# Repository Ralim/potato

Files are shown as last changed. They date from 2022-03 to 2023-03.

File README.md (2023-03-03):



# Potato

OpenSource inline USB-PD Power meter.

...WIP...

## Desired features

- Easy to assemble (No QFN)
- Read device PD capabilities
- Capture USB-PD messages
- Read USB D- / D+ voltages for QC
- Pull resistors for QC control
- UART or USB for datalogging
- Either buttons or encoder for input
- Small LCD display
- DC In/Out port

- Accelerometer or tilt switch for rotation?

## Ideas to explore

- As LVGL is a goal for the UI, consider [prototyping](https://docs.lvgl.io/latest/en/html/get-started/pc-simulator.html) on "real" computer or talking to the PineTime team about their experience about developing [UI in NaCL](https://github.com/AppKaki/lvgl-wasm), allowing feedback from web users. If realized, this may allow more explorative development in a less painful environment as you can skip the slow upload/reboot cycle.

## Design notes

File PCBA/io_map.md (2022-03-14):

Here is the first pass of or [gpio pin mapping](https://user-images.githubusercontent.com/8724975/158108831-fbf8fa47-cd49-4bae-8a7a-24a997bb3a8b.png).

This comes from mcu.kicad_sch, but is broken out for discussion and to be of more immediate use to 
those not versed in Kicad.

As of March 14, Robert is uncomfortable with Pin 16. (Robert's a software guy, so his uneasiness is 
trumped by other boards successfully using Pint 16.) Section 3.2.5 on page 25 describes the versaitle 
pin muxing available on the BL60x parts. It shows that we can populate the five bit mode enum to bring 
it into UART mode.  UNfortunately, the pins default to UART mode SIG1, which maps to UART0_CTS when 
a SIG6 would give us a compliment to our UART1_RX currently on GPIO 7.

Trying to harvest from current code is frustrating.

~/src/bl_mcu_sdk/drivers/bl602_driver/regs/glb_reg.h 
creates a perfectly lovely bitmapped union, which the code signores and splats over its own 
incomprehensible macros and bit-banging.  uart-swap_set is never used. The bits are actually 
set in GLB_UART_Sig_Swap_Set() inside drivers/bl602_driver/std_drv/src/bl602_glb.c

So we're currently researching this. Help welcome.



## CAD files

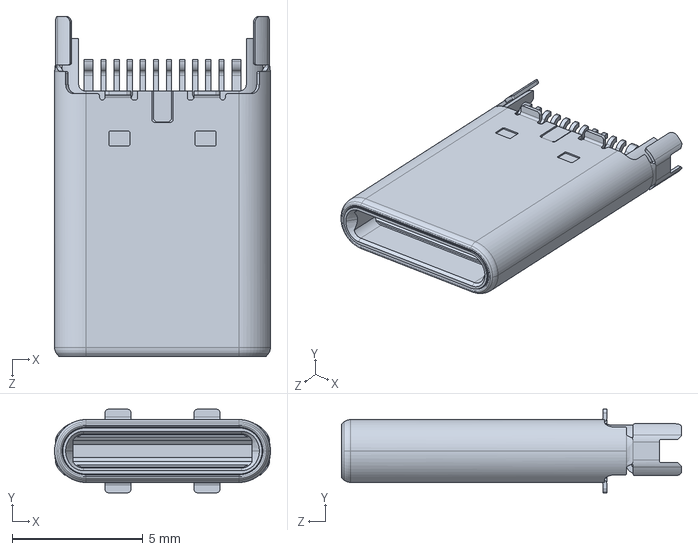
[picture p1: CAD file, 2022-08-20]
PCBA/K3D-DX07P022AA6.STEP
8.25 x 3.20 x 13.0 mm

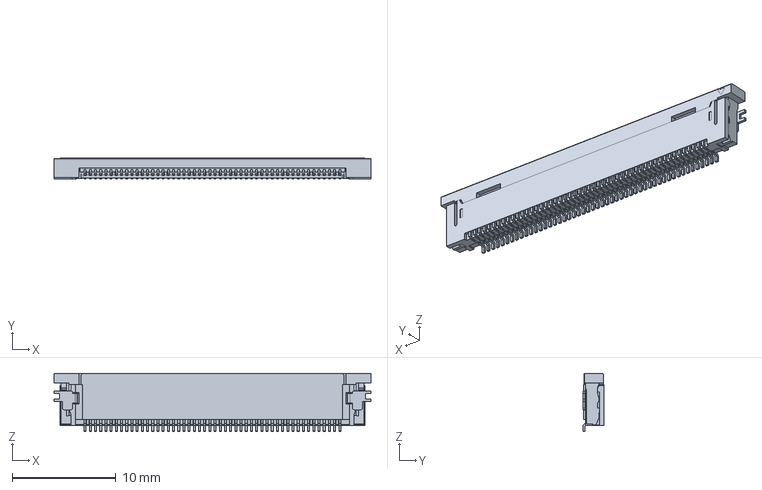
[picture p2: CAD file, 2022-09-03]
PCBA/541325033.stp
30.5 x 2.05 x 5.60 mm

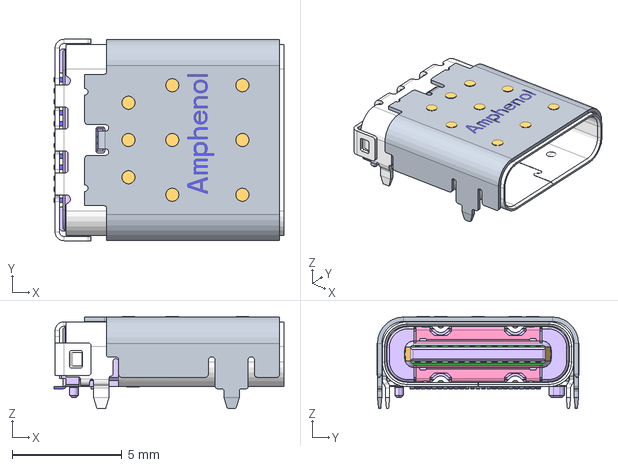
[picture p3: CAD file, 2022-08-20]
PCBA/12401610E4#2A--3DModel-STEP-533217.STEP
10.5 x 9.20 x 4.21 mm

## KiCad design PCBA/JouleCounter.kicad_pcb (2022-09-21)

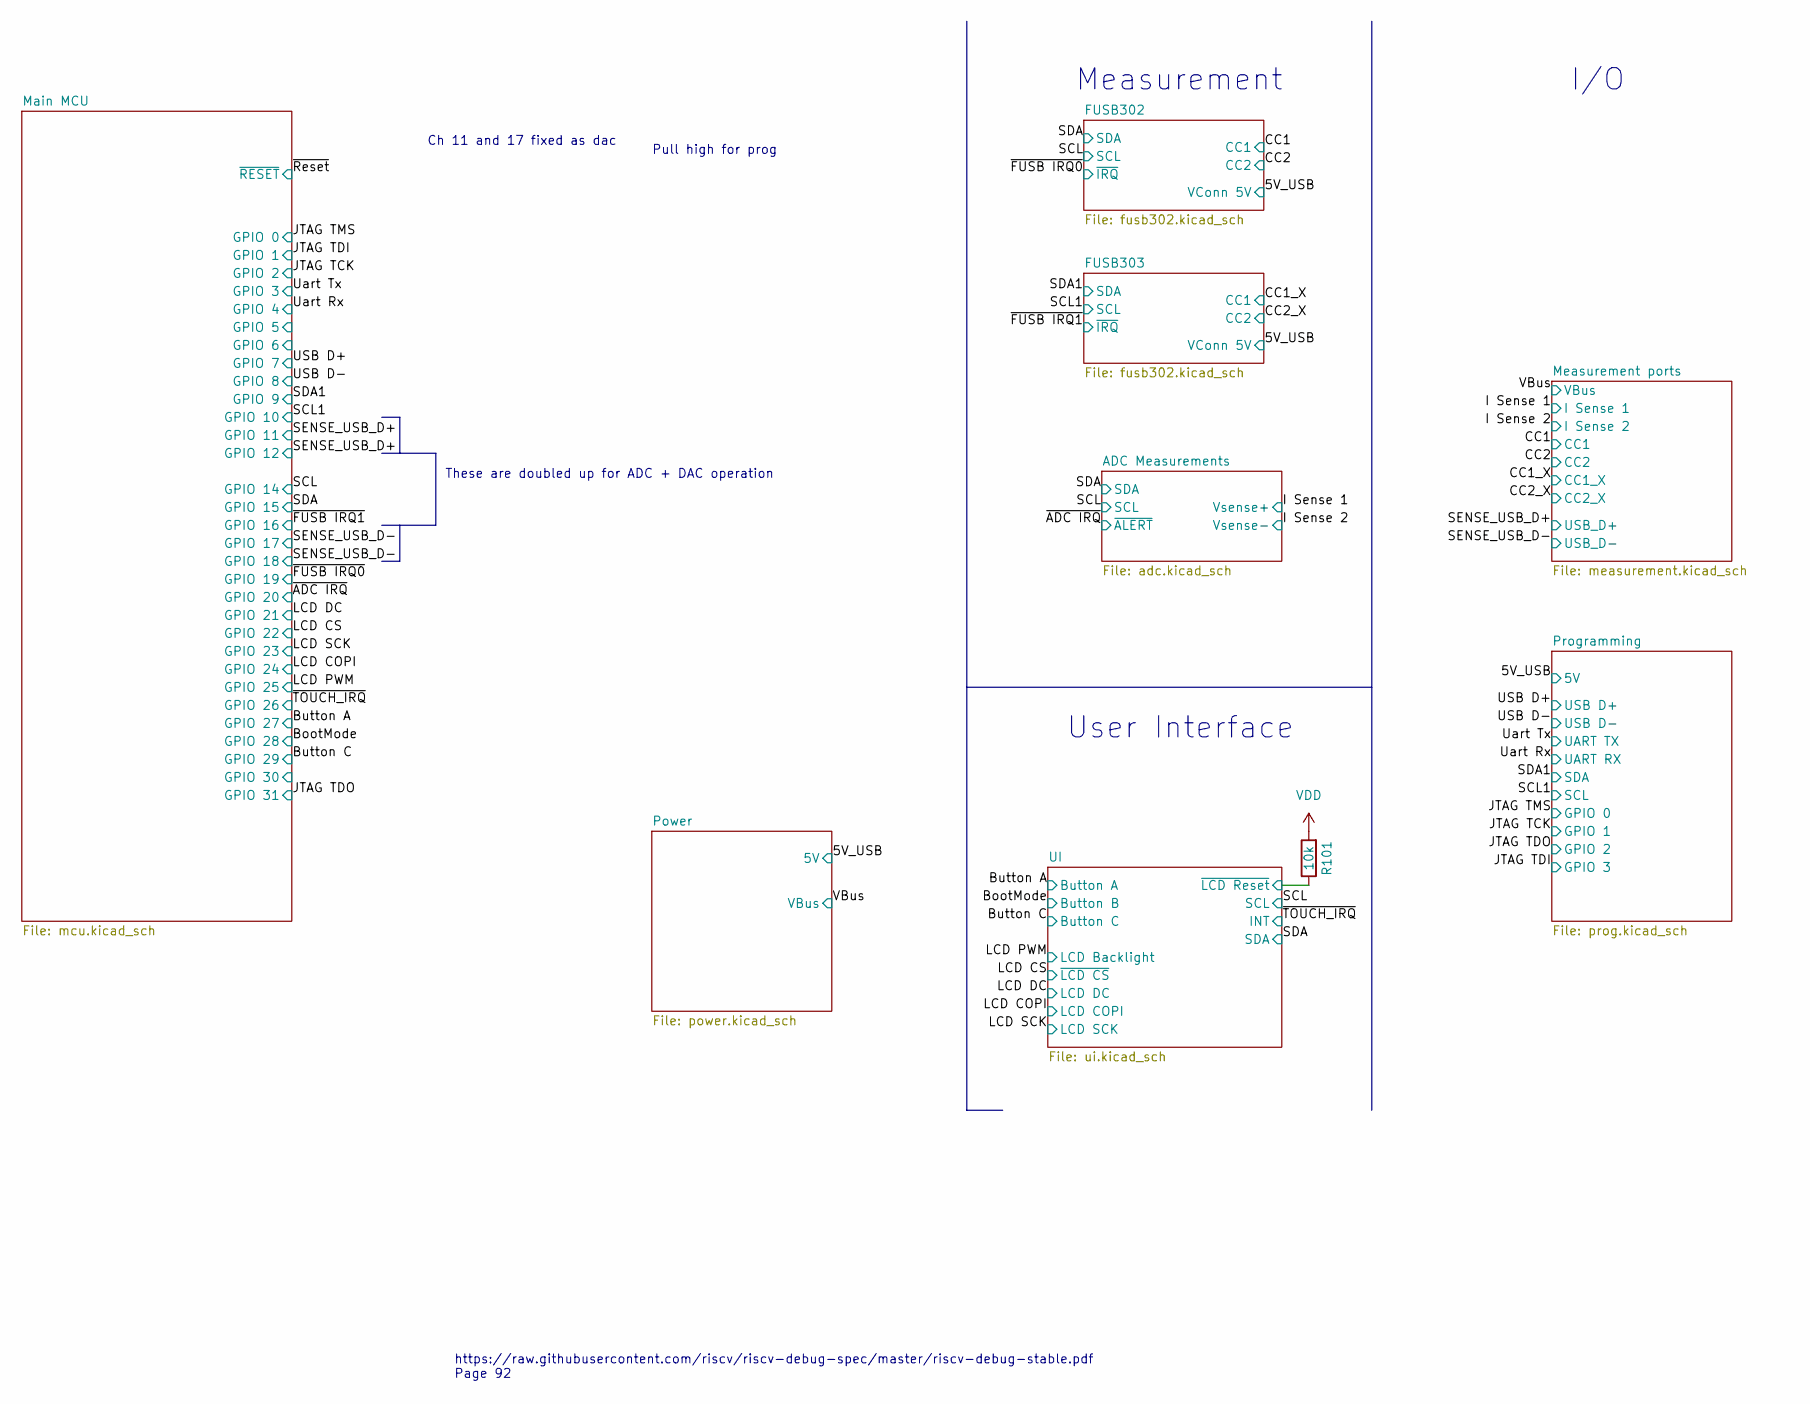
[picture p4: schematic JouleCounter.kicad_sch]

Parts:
R101: 10k; R_0603_1608Metric

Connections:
/UI/~LCD Reset: R101.1; also elsewhere on the board
VDD: R101.2; also elsewhere on the board

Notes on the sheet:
Measurement
Pull high for prog
I/O
Ch 11 and 17 fixed as dac
https://raw.githubusercontent.com/riscv/riscv-debug-spec/master/riscv-debug-stable.pdf Page 92
These are doubled up for ADC + DAC operation
User Interface

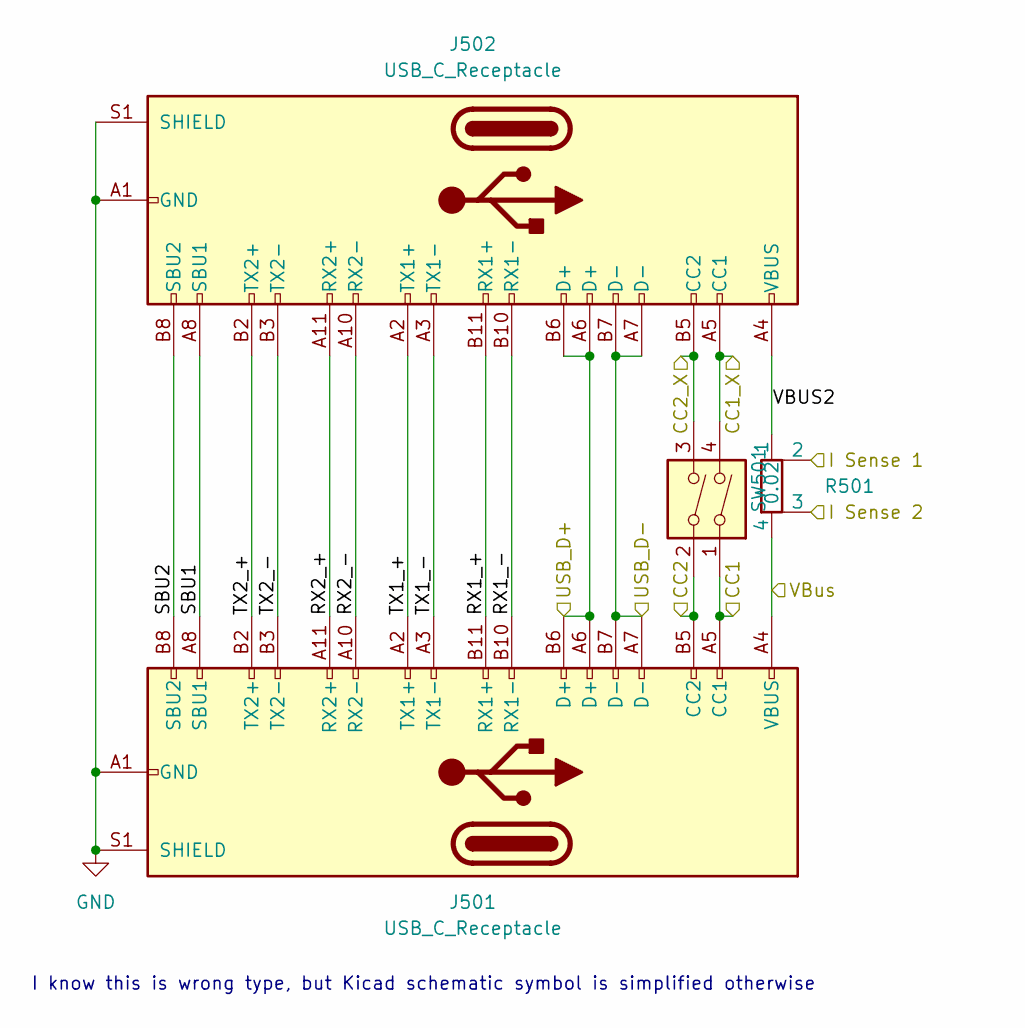
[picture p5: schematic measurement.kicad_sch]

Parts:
J501: USB_C_Receptacle; USB_C_Plug_JAE_DX07P024AJ1
J502: USB_C_Receptacle; USB_C_Receptacle_Amphenol_12401610E4-2A
R501: 0.02; R_Shunt_Vishay_WSK2512_6332Metric_T1.19mm
SW501: SW_DIP_x02; SW_DIP_SPSTx02_Slide_Copal_CHS-02A_W5.08mm_P1.27mm_JPin

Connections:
/CC1: J501.A5 (CC1), SW501.1; also elsewhere on the board
/CC1_X: J502.A5 (CC1), SW501.4; also elsewhere on the board
/CC2: J501.B5 (CC2), SW501.2; also elsewhere on the board
/CC2_X: J502.B5 (CC2), SW501.3; also elsewhere on the board
/I Sense 1: R501.2; also elsewhere on the board
/I Sense 2: R501.3; also elsewhere on the board
/Measurement ports/RX1_+: J501.B11 (RX1+), J502.B11 (RX1+)
/Measurement ports/RX1_-: J501.B10 (RX1-), J502.B10 (RX1-)
/Measurement ports/RX2_+: J501.A11 (RX2+), J502.A11 (RX2+)
/Measurement ports/RX2_-: J501.A10 (RX2-), J502.A10 (RX2-)
/Measurement ports/SBU1: J501.A8 (SBU1), J502.A8 (SBU1)
/Measurement ports/SBU2: J501.B8 (SBU2), J502.B8 (SBU2)
/Measurement ports/TX1_+: J501.A2 (TX1+), J502.A2 (TX1+)
/Measurement ports/TX1_-: J501.A3 (TX1-), J502.A3 (TX1-)
/Measurement ports/TX2_+: J501.B2 (TX2+), J502.B2 (TX2+)
/Measurement ports/TX2_-: J501.B3 (TX2-), J502.B3 (TX2-)
/Measurement ports/VBUS2: J502.A4 (VBUS), J502.A9 (VBUS), J502.B4 (VBUS), J502.B9 (VBUS), R501.1
/SENSE_USB_D+: J501.A6 (D+), J501.B6 (D+), J502.A6 (D+), J502.B6 (D+); also elsewhere on the board
/SENSE_USB_D-: J501.A7 (D-), J501.B7 (D-), J502.A7 (D-), J502.B7 (D-); also elsewhere on the board
/VBus: J501.A4 (VBUS), J501.A9 (VBUS), J501.B4 (VBUS), J501.B9 (VBUS), R501.4; also elsewhere on the board
GND: J501.A1 (GND), J501.A12 (GND), J501.B1 (GND), J501.B12 (GND), J501.S1 (SHIELD), J502.A1 (GND), J502.A12 (GND), J502.B1 (GND), J502.B12 (GND), J502.S1 (SHIELD); also elsewhere on the board

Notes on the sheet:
I know this is wrong type, but Kicad schematic symbol is simplified otherwise

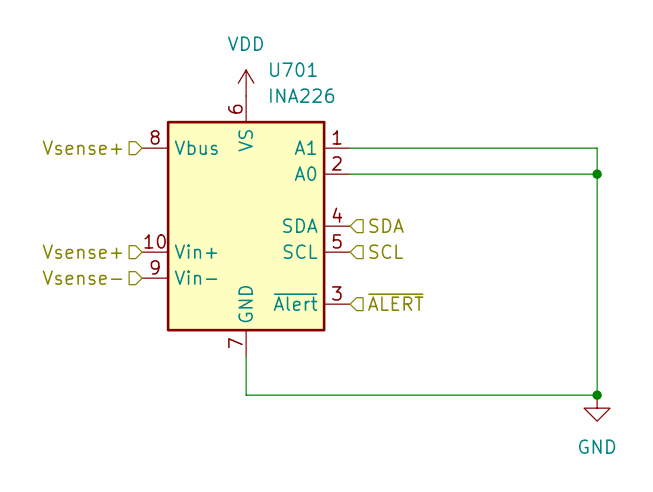
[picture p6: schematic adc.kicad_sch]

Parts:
U701: INA226; VSSOP-10_3x3mm_P0.5mm

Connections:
/I Sense 1: U701.8 (Vbus), U701.10 (Vin+); also elsewhere on the board
/I Sense 2: U701.9 (Vin-); also elsewhere on the board
/SCL: U701.5 (SCL); also elsewhere on the board
/SDA: U701.4 (SDA); also elsewhere on the board
/~ADC IRQ: U701.3 (~Alert); also elsewhere on the board
GND: U701.1 (A1), U701.2 (A0), U701.7 (GND); also elsewhere on the board
VDD: U701.6 (VS); also elsewhere on the board

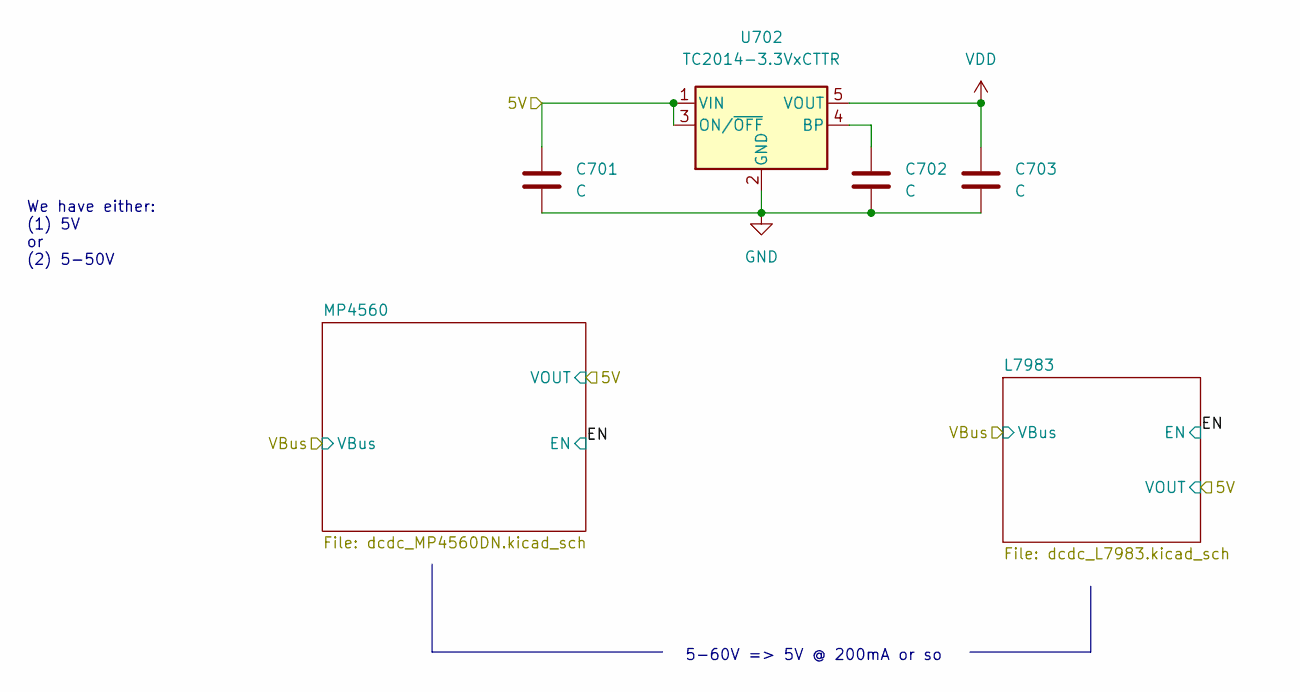
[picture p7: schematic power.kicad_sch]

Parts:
C701, C702, C703: C; C_0603_1608Metric
U702: TC2014-3.3VxCTTR; SOT-23-5

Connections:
/5V_USB: C701.1, U702.1 (VIN), U702.3 (ON/~OFF); also elsewhere on the board
GND: C701.2, C702.2, C703.2, U702.2 (GND); also elsewhere on the board
unnamed: C702.1, U702.4 (BP)
VDD: C703.1, U702.5 (VOUT); also elsewhere on the board

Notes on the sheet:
We have either: (1) 5V or (2) 5-50V
5-60V => 5V @ 200mA or so

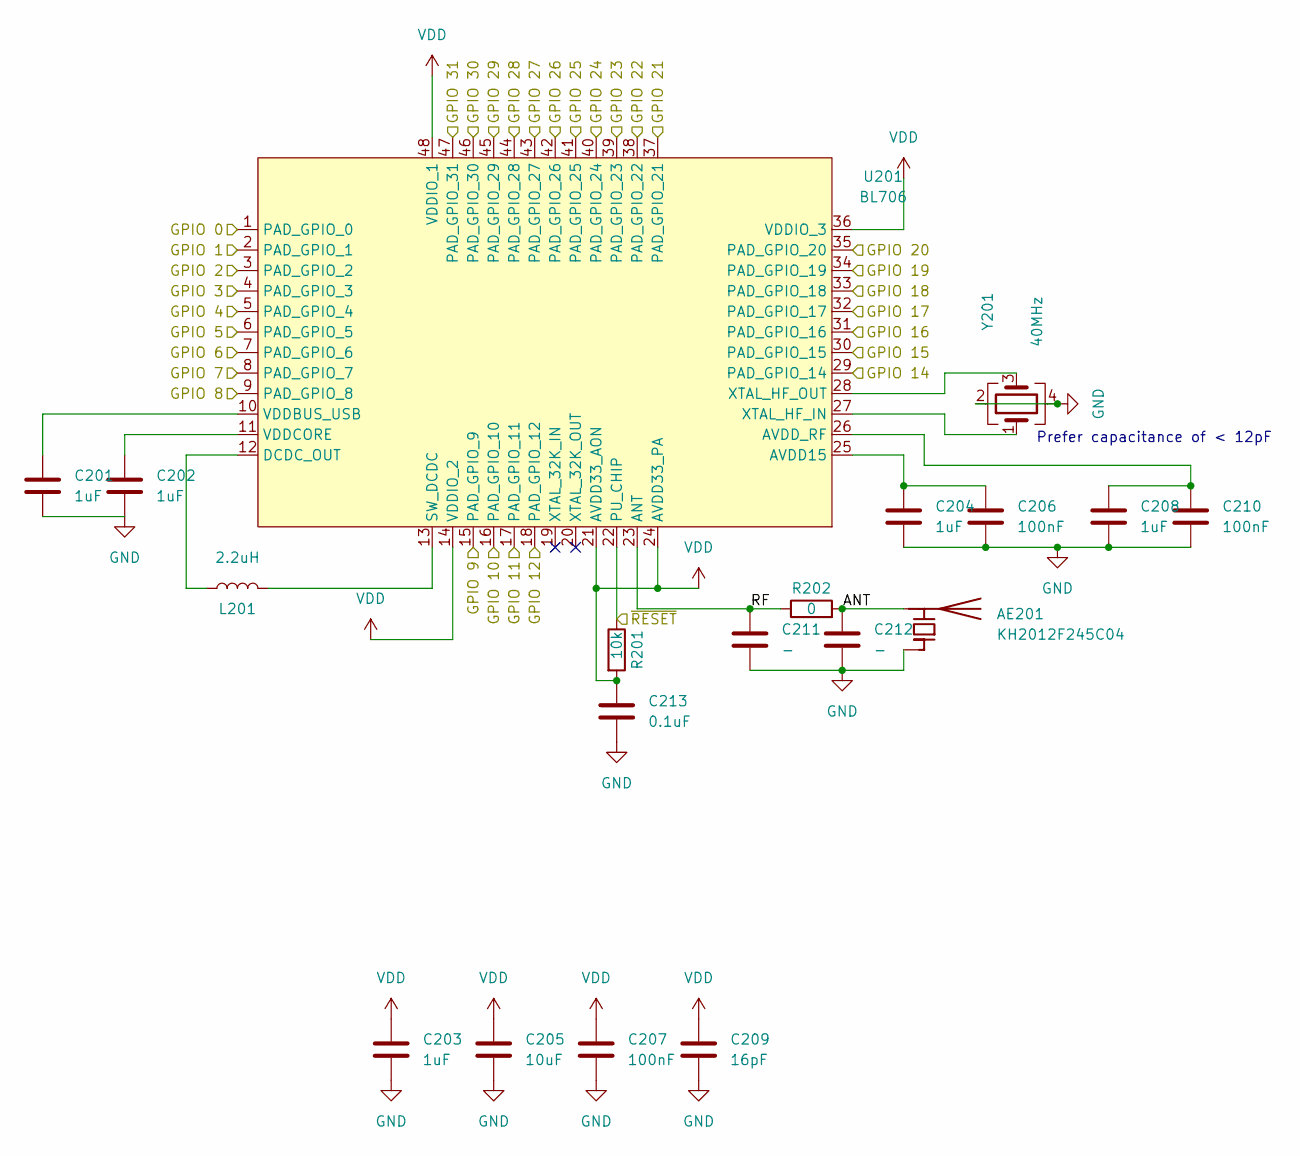
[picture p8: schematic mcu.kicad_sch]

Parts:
AE201: KH2012F245C04; R_0805_2012Metric
C201, C202, C203, C204, C208: 1uF; C_0603_1608Metric
C205: 10uF; C_0603_1608Metric
C206, C207, C210: 100nF; C_0603_1608Metric
C209: 16pF; C_0603_1608Metric
C211, C212: -; C_0603_1608Metric
C213: 0.1uF; C_0603_1608Metric
L201: 2.2uH; L_0805_2012Metric
R201: 10k; R_0603_1608Metric
R202: 0; R_0603_1608Metric
U201: BL706; QFN-48-1EP_6x6mm_P0.4mm_EP4.2x4.2mm
Y201: 40MHz; Crystal_SMD_2016-4Pin_2.0x1.6mm

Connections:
/BootMode: U201.44 (PAD_GPIO_28); also elsewhere on the board
/Button A: U201.43 (PAD_GPIO_27); also elsewhere on the board
/Button C: U201.45 (PAD_GPIO_29); also elsewhere on the board
/JTAG TCK: U201.3 (PAD_GPIO_2); also elsewhere on the board
/JTAG TDI: U201.2 (PAD_GPIO_1); also elsewhere on the board
/JTAG TDO: U201.47 (PAD_GPIO_31); also elsewhere on the board
/JTAG TMS: U201.1 (PAD_GPIO_0); also elsewhere on the board
/LCD COPI: U201.40 (PAD_GPIO_24); also elsewhere on the board
/LCD CS: U201.38 (PAD_GPIO_22); also elsewhere on the board
/LCD DC: U201.37 (PAD_GPIO_21); also elsewhere on the board
/LCD PWM: U201.41 (PAD_GPIO_25); also elsewhere on the board
/LCD SCK: U201.39 (PAD_GPIO_23); also elsewhere on the board
/Main MCU/ANT: AE201.2 (PCB_Trace), C212.1, R202.2
/Main MCU/GPIO 5: U201.6 (PAD_GPIO_5)
/Main MCU/GPIO 6: U201.7 (PAD_GPIO_6)
/Main MCU/GPIO 30: U201.46 (PAD_GPIO_30)
/Main MCU/RF: C211.1, R202.1, U201.23 (ANT)
/SCL: U201.29 (PAD_GPIO_14); also elsewhere on the board
/SCL1: U201.16 (PAD_GPIO_10); also elsewhere on the board
/SDA: U201.30 (PAD_GPIO_15); also elsewhere on the board
/SDA1: U201.15 (PAD_GPIO_9); also elsewhere on the board
/SENSE_USB_D+: U201.17 (PAD_GPIO_11), U201.18 (PAD_GPIO_12); also elsewhere on the board
/SENSE_USB_D-: U201.32 (PAD_GPIO_17), U201.33 (PAD_GPIO_18); also elsewhere on the board
/USB D+: U201.8 (PAD_GPIO_7); also elsewhere on the board
/USB D-: U201.9 (PAD_GPIO_8); also elsewhere on the board
/Uart Rx: U201.5 (PAD_GPIO_4); also elsewhere on the board
/Uart Tx: U201.4 (PAD_GPIO_3); also elsewhere on the board
/~ADC IRQ: U201.35 (PAD_GPIO_20); also elsewhere on the board
/~FUSB IRQ0: U201.34 (PAD_GPIO_19); also elsewhere on the board
/~FUSB IRQ1: U201.31 (PAD_GPIO_16); also elsewhere on the board
/~Reset: R201.1, U201.22 (PU_CHIP)
/~TOUCH_IRQ: U201.42 (PAD_GPIO_26); also elsewhere on the board
GND: AE201.1 (FEED), C201.2, C202.2, C203.2, C204.2, C205.2, C206.2, C207.2, C208.2, C209.2, C210.2, C211.2, C212.2, C213.2, Y201.2, Y201.4; also elsewhere on the board
unnamed: C201.1, U201.10 (VDDBUS_USB)
unnamed: C202.1, U201.11 (VDDCORE)
unnamed: C204.1, C206.1, U201.25 (AVDD15)
unnamed: C208.1, C210.1, U201.26 (AVDD_RF)
unnamed: L201.1, U201.12 (DCDC_OUT)
unnamed: L201.2, U201.13 (SW_DCDC)
unnamed: U201.27 (XTAL_HF_IN), Y201.1
unnamed: U201.28 (XTAL_HF_OUT), Y201.3
VDD: C203.1, C205.1, C207.1, C209.1, C213.1, R201.2, U201.14 (VDDIO_2), U201.21 (AVDD33_AON), U201.24 (AVDD33_PA), U201.36 (VDDIO_3), U201.48 (VDDIO_1); also elsewhere on the board

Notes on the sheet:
Prefer capacitance of < 12pF

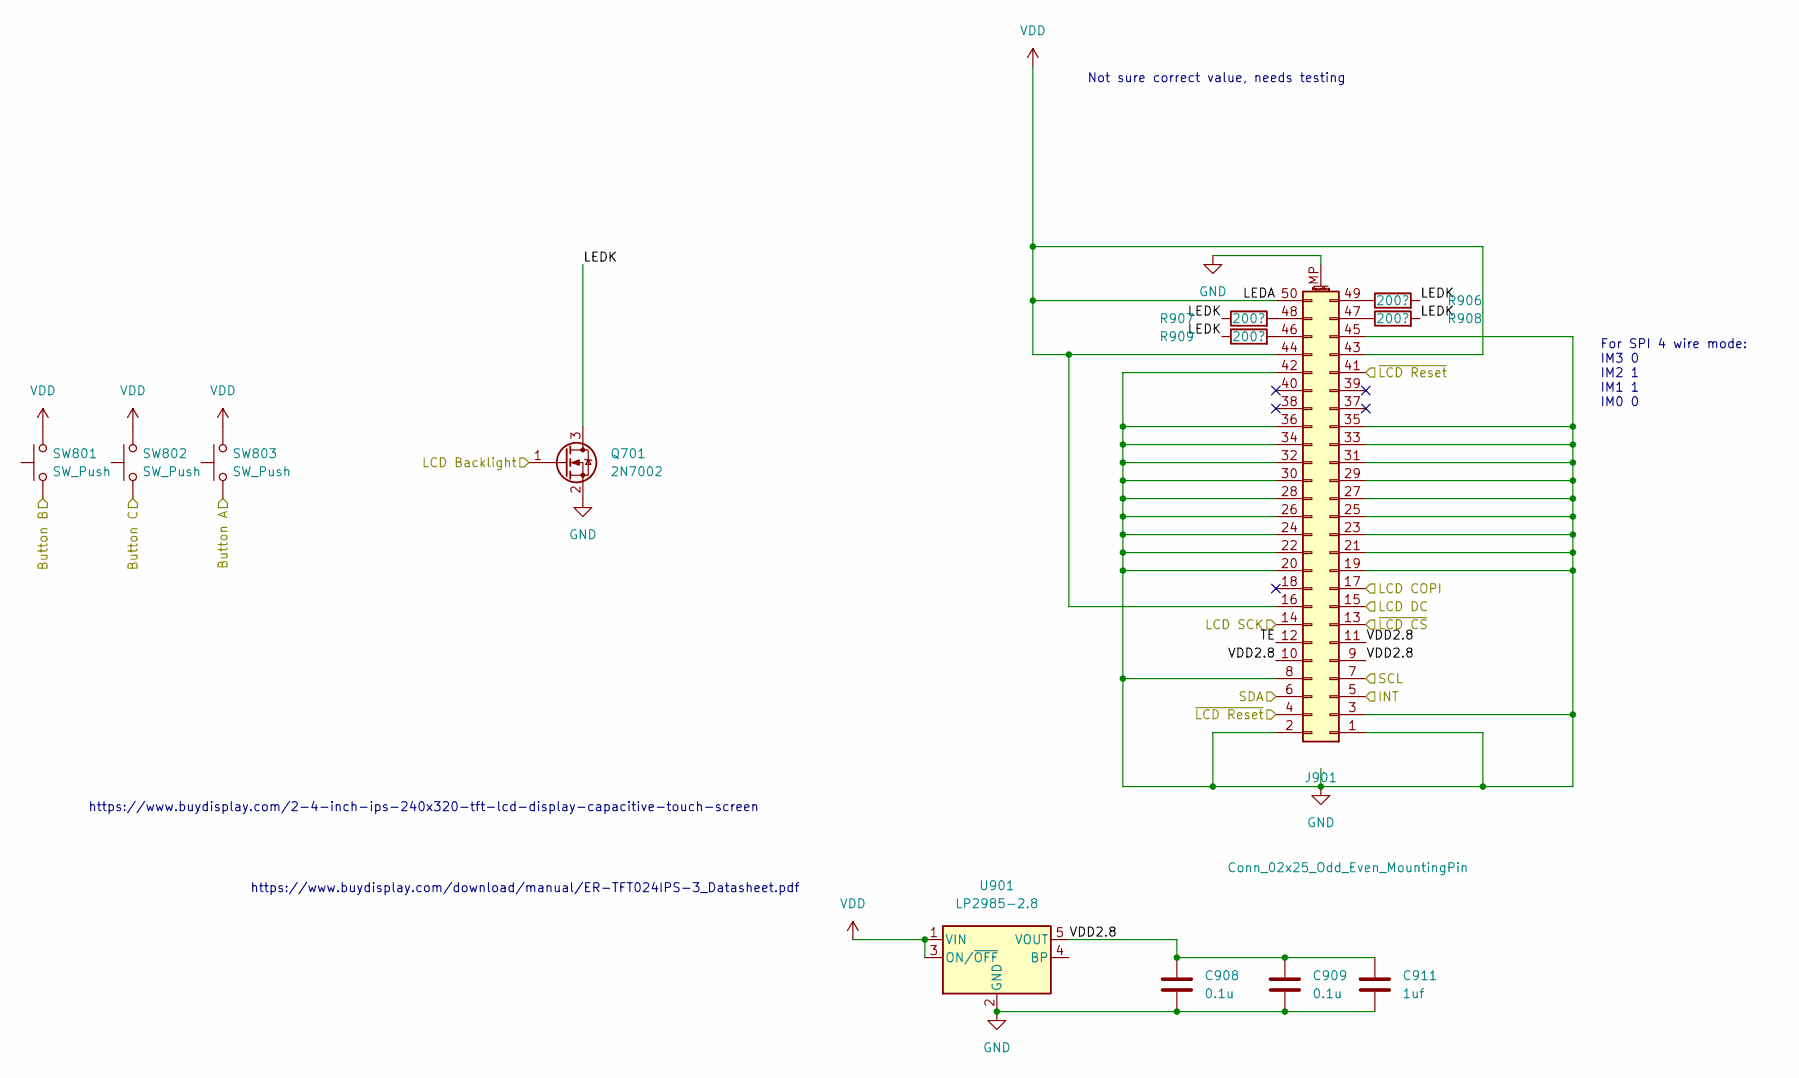
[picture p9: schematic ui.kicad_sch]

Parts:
C908, C909: 0.1u; C_0603_1608Metric
C911: 1uf; C_0603_1608Metric
J901: Conn_02x25_Odd_Even_MountingPin; Molex_54132-5033_1x50-1MP_P0.5mm_Horizontal
Q701: 2N7002; SOT-23
R906, R907, R908, R909: 200?; R_0603_1608Metric
SW801, SW802, SW803: SW_Push; SW_Tactile_SKHH_Angled
U901: LP2985-2.8; SOT-23-5

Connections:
/BootMode: SW801.1; also elsewhere on the board
/Button A: SW803.1; also elsewhere on the board
/Button C: SW802.1; also elsewhere on the board
/LCD COPI: J901.17; also elsewhere on the board
/LCD CS: J901.13; also elsewhere on the board
/LCD DC: J901.15; also elsewhere on the board
/LCD PWM: Q701.1 (G); also elsewhere on the board
/LCD SCK: J901.14; also elsewhere on the board
/SCL: J901.7; also elsewhere on the board
/SDA: J901.6; also elsewhere on the board
/UI/LEDK: Q701.3 (D), R906.2, R907.1, R908.2, R909.1
/UI/TE: J901.12
/UI/VDD2.8: C908.1, C909.1, C911.1, J901.9, J901.10, J901.11, U901.5 (VOUT)
/UI/~LCD Reset: J901.4, J901.41; also elsewhere on the board
/~TOUCH_IRQ: J901.5; also elsewhere on the board
GND: C908.2, C909.2, C911.2, J901.1, J901.2, J901.3, J901.8, J901.19, J901.20, J901.21, J901.22, J901.23, J901.24, J901.25, J901.26, J901.27, J901.28, J901.29, J901.30, J901.31, J901.32, J901.33, J901.34, J901.35, J901.36, J901.42, J901.45, J901.MP (MountPin), Q701.2 (S), U901.2 (GND); also elsewhere on the board
unnamed: J901.46, R909.2
unnamed: J901.47, R908.1
unnamed: J901.48, R907.2
unnamed: J901.49, R906.1
VDD: J901.16, J901.43, J901.44, J901.50, SW801.2, SW802.2, SW803.2, U901.1 (VIN), U901.3 (ON/~OFF); also elsewhere on the board

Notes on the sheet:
Not sure correct value, needs testing
https://www.buydisplay.com/2-4-inch-ips-240x320-tft-lcd-display-capacitive-touch-screen
For SPI 4 wire mode: IM3 0 IM2 1 IM1 1 IM0 0
https://www.buydisplay.com/download/manual/ER-TFT024IPS-3_Datasheet.pdf

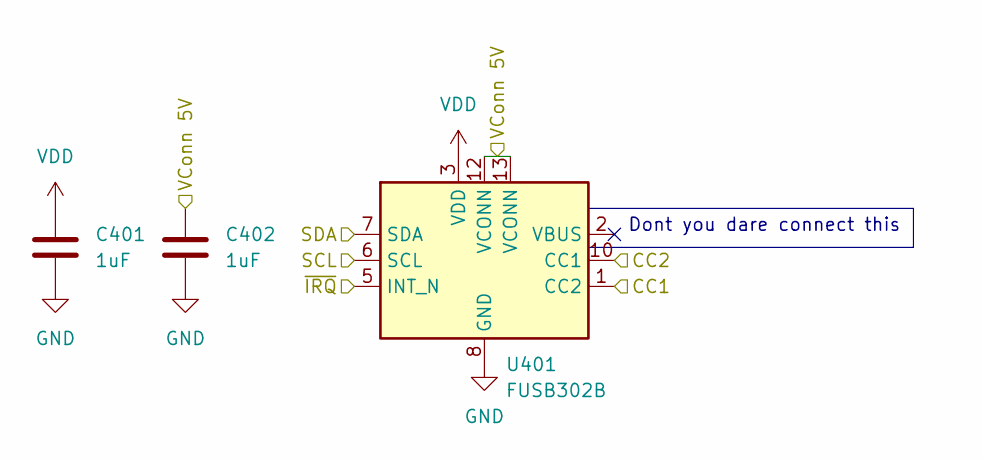
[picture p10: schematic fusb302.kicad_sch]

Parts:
C401, C402: 1uF; C_0603_1608Metric
U401: FUSB302B; WQFN-14-1EP_2.5x2.5mm_P0.5mm_EP1.45x1.45mm

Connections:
/5V_USB: C402.1, U401.12 (VCONN), U401.13 (VCONN); also elsewhere on the board
/CC1: U401.1 (CC2), U401.14 (CC2); also elsewhere on the board
/CC2: U401.10 (CC1), U401.11 (CC1); also elsewhere on the board
/SCL: U401.6 (SCL); also elsewhere on the board
/SDA: U401.7 (SDA); also elsewhere on the board
/~FUSB IRQ0: U401.5 (INT_N); also elsewhere on the board
GND: C401.2, C402.2, U401.8 (GND), U401.9 (GND), U401.15 (GND); also elsewhere on the board
VDD: C401.1, U401.3 (VDD), U401.4 (VDD); also elsewhere on the board

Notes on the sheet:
Dont you dare connect this

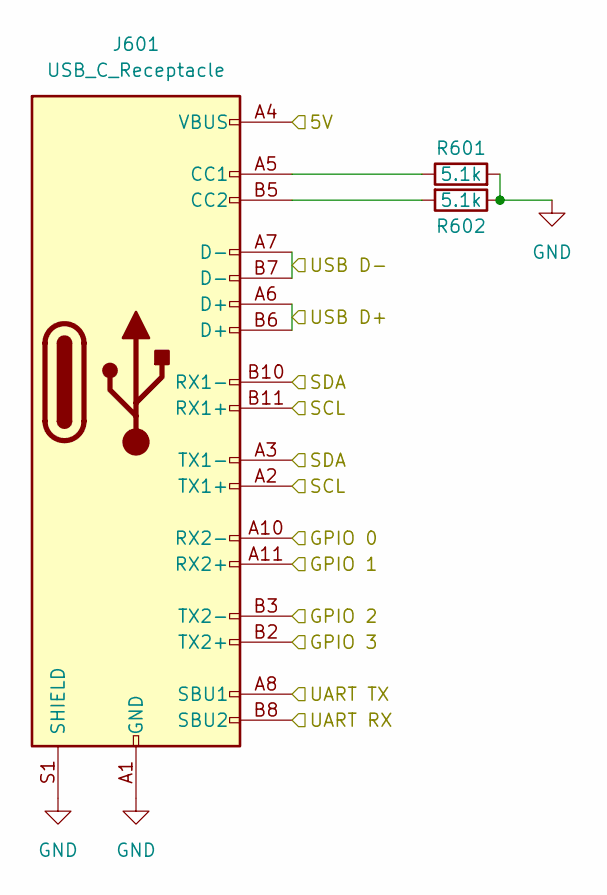
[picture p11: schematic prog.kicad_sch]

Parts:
J601: USB_C_Receptacle; USB_C_Receptacle_Amphenol_12401610E4-2A
R601, R602: 5.1k; R_0603_1608Metric

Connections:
/5V_USB: J601.A4 (VBUS), J601.A9 (VBUS), J601.B4 (VBUS), J601.B9 (VBUS); also elsewhere on the board
/JTAG TCK: J601.A11 (RX2+); also elsewhere on the board
/JTAG TDI: J601.B2 (TX2+); also elsewhere on the board
/JTAG TDO: J601.B3 (TX2-); also elsewhere on the board
/JTAG TMS: J601.A10 (RX2-); also elsewhere on the board
/SCL1: J601.A2 (TX1+), J601.B11 (RX1+); also elsewhere on the board
/SDA1: J601.A3 (TX1-), J601.B10 (RX1-); also elsewhere on the board
/USB D+: J601.A6 (D+), J601.B6 (D+); also elsewhere on the board
/USB D-: J601.A7 (D-), J601.B7 (D-); also elsewhere on the board
/Uart Rx: J601.B8 (SBU2); also elsewhere on the board
/Uart Tx: J601.A8 (SBU1); also elsewhere on the board
GND: J601.A1 (GND), J601.A12 (GND), J601.B1 (GND), J601.B12 (GND), J601.S1 (SHIELD), R601.2, R602.1; also elsewhere on the board
unnamed: J601.A5 (CC1), R601.1
unnamed: J601.B5 (CC2), R602.2

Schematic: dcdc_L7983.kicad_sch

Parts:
C1001: 100nF; C_0603_1608Metric
C1002, C1003, C1004: 2.2uF; C_0603_1608Metric
C1005: C; C_0603_1608Metric
IC1001: L7983PU33R; Manufacturer_Part_Number L7983PU33R; Mouser Part Number 511-L7983PU33R
L1001: 47uH; L_1210_3225Metric
R1001, R1003: 0; R_0603_1608Metric
R1002: DNP; R_0603_1608Metric
R1004: 100k; R_0603_1608Metric
R1005: 180k; R_0603_1608Metric
R1006: 68k; R_0603_1608Metric

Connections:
/5V_USB: C1003.1, C1004.1, L1001.2, R1005.1; also elsewhere on the board
/Power/EN: IC1001.7 (EN/UVLO); also elsewhere on the board
/Power/L7983/Lx: IC1001.9 (LX), L1001.1
/VBus: C1005.1, IC1001.8 (VIN); also elsewhere on the board
GND: C1001.2, C1002.2, C1003.2, C1005.2, IC1001.5 (LNM/~LCM), IC1001.10 (GND), IC1001.11 (E.P.), R1002.2, R1006.2; also elsewhere on the board
unnamed: C1001.1, IC1001.2 (VBIAS), R1001.2, R1002.1
unnamed: C1002.1, IC1001.3 (VCC), R1003.1, R1004.1
unnamed: C1004.2, IC1001.1 (VOUT/FB), R1001.1, R1005.2, R1006.1
unnamed: IC1001.4 (FSW), R1003.2
unnamed: IC1001.6 (~RST), R1004.2

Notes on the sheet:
https://www.lcsc.com/product-detail/Inductors-SMD_TDK-NLCV32T-470K-PF_C83083.html

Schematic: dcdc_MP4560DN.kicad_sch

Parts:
C901: 47uF; C_0603_1608Metric
C902, C906: 4.7uF; C_0603_1608Metric
C903, C904: -; C_0603_1608Metric
C905: 100nF; C_0603_1608Metric
D901: D_Schottky; D_SOD-323
IC901: MP4560DN-LF-Z; SOIC127P600X170-9N; Manufacturer_Part_Number MP4560DN-LF-Z; Mouser Part Number 946-MP4560DNLFZ
L901: 15; L_Wuerth_MAPI-3010
R901, R904, R905: 200k; R_0603_1608Metric
R902, R903: -; R_0603_1608Metric

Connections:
/5V_USB: C901.2, C902.2, L901.1, R901.1; also elsewhere on the board
/Power/EN: IC901.2 (EN), R904.1; also elsewhere on the board
/VBus: C906.2, IC901.7 (VIN), R904.2; also elsewhere on the board
GND: C901.1, C902.1, C904.1, C906.1, D901.2 (A), IC901.5 (GND), IC901.9 (EP), R902.2, R903.2, R905.2; also elsewhere on the board
unnamed: C903.1, R903.1
unnamed: C903.2, C904.2, IC901.3 (COMP)
unnamed: C905.1, D901.1 (K), IC901.1 (SW), L901.2
unnamed: C905.2, IC901.8 (BST)
unnamed: IC901.4 (FB), R901.2, R902.1
unnamed: IC901.6 (FREQ), R905.1

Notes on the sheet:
https://lcsc.com/product-detail/Power-Inductors_CENKER-CKCS3012-15uH-M_C354559.html

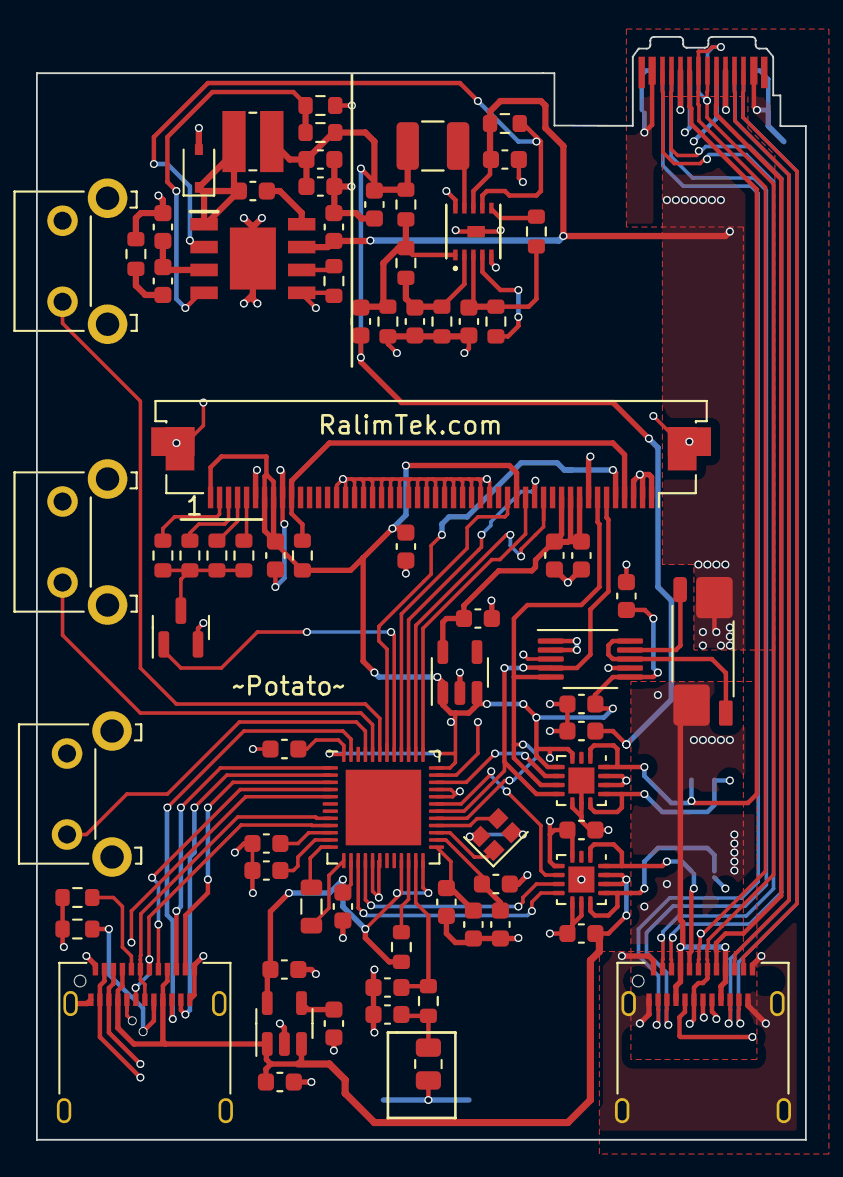
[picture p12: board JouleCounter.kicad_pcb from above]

Board: 4 copper layers, 42.7 x 61.3 mm, 78 parts (1 on the bottom side), 81 nets.

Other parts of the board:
C301, C302: 1uF; C_0603_1608Metric
U301: FUSB302B; WQFN-14-1EP_2.5x2.5mm_P0.5mm_EP1.45x1.45mm

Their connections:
/5V_USB: C302.1, U301.12 (VCONN), U301.13 (VCONN); also elsewhere on the board
/CC1_X: U301.1 (CC2), U301.14 (CC2); also elsewhere on the board
/CC2_X: U301.10 (CC1), U301.11 (CC1); also elsewhere on the board
/SCL1: U301.6 (SCL); also elsewhere on the board
/SDA1: U301.7 (SDA); also elsewhere on the board
/~FUSB IRQ1: U301.5 (INT_N); also elsewhere on the board
GND: C301.2, C302.2, U301.8 (GND), U301.9 (GND), U301.15 (GND); also elsewhere on the board
VDD: C301.1, U301.3 (VDD), U301.4 (VDD); also elsewhere on the board

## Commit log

2022-03-03 Create BL604 symbol
    [JouleCounter.kicad_pcb, JouleCounter.kicad_sch]
2022-03-03 Scratching out schematic
    [Flash.kicad_sch, JouleCounter.kicad_sch, fusb302.kicad_sch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]
2022-03-03 Input/output jacks
    [JouleCounter.kicad_sch, measurement.kicad_sch]
2022-03-03 Programming uart added
    [JouleCounter.kicad_sch, mcu.kicad_sch, prog.kicad_sch]
2022-03-03 ADC readings
    [JouleCounter.kicad_sch, adc.kicad_sch, mcu.kicad_sch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]
2022-03-03 TODO: usb c plug
    [JouleCounter.kicad_sch, measurement.kicad_sch]
2022-03-04 Right usb end
    [JouleCounter.kicad_sch, measurement.kicad_sch]
2022-03-04 More schematics
    [JouleCounter.kicad_pcb, JouleCounter.kicad_sch, adc.kicad_sch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]
2022-03-05 Add link to screen
    [ui.kicad_sch]
2022-03-05 Add Qwiic
    [JouleCounter.kicad_sch, ui.kicad_sch]
2022-03-05 Start adding power
    [JouleCounter.kicad_sch, power.kicad_sch]
2022-03-13 Adding DC/DC layout
    [JouleCounter.kicad_sch, power.kicad_sch]
2022-03-13 GPIO association pass 1
    [JouleCounter.kicad_sch]
2022-03-14 Propose accelerometer
2022-03-26 Add MP4560 schematic symbol+footprint
    [JouleCounter.kicad_sch, dcdc_L7983.kicad_sch, dcdc_MP4560DN.kicad_sch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]
2022-03-27 Finish MP schematic
    [JouleCounter.kicad_sch, dcdc_MP4560DN.kicad_sch, power.kicad_sch]
2022-03-27 Assign footprints
    [JouleCounter.kicad_pcb, JouleCounter.kicad_sch, dcdc_L7983.kicad_sch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]
2022-08-10 Update schematic pinmap bl706
    [JouleCounter.kicad_pcb, JouleCounter.kicad_sch, fusb302.kicad_sch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]
2022-08-20 Rough outline
    [JouleCounter.kicad_pcb, JouleCounter.kicad_sch, dcdc_L7983.kicad_sch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]
2022-08-20 More rough placement
    [JouleCounter.kicad_pcb, JouleCounter.kicad_sch, fusb302.kicad_sch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]
2022-08-20 Step models for ports
    [12401610E4#2A--3DModel-STEP-533217.STEP, JouleCounter.kicad_pcb, JouleCounter.kicad_sch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]
2022-09-03 PCB size
    [JouleCounter.kicad_pcb]
2022-09-03 molex model
    [541325033.stp, JouleCounter.kicad_pcb, JouleCounter.kicad_sch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]
2022-09-03 Jtag on usb-c
    [JouleCounter.kicad_pcb, JouleCounter.kicad_sch, fusb302.kicad_sch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]
2022-09-10 Finish routing
    [JouleCounter.kicad_pcb, JouleCounter.kicad_sch, fusb302.kicad_sch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]
2022-09-21 Fix up via hole size
    [JouleCounter.kicad_pcb]
